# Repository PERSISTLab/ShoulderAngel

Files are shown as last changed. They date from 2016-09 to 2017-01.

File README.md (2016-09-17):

# Shoulder Angel: An Open Platform for Reprogramming Wayward Wireless Sensors

Software bugs are a critical threat to the deployability and maintainability of low-power wireless sensors, resulting in excess power consumption, hardware misconfigurations, incorrect data, and shortened device lifetimes. Worse, these errors can prevent wireless reprogramming, resulting in longer delays and costly human interventions. This repository contains the  Shoulder Angel—an ultra-low-power, low-cost, open hardware and software platform that ensures users can always recover and reprogram wireless sensors, in spite of software errors. Shoulder Angel uses a physically separate coprocessor to monitor a device’s power consumption and other behaviors, while keeping the device in a reprogrammable state. Our results show that Shoulder Angel is able to recover from otherwise fatal software errors while incurring an energy overhead of only 7 μW.

### Getting Started
Coming soon....

### License

```
Copyright (c) 2016 PERSIST Lab

Permission is hereby granted, free of charge, to any person obtaining a copy of this software 
and associated documentation files (the "Software"), to deal in the Software without restriction, 
including without limitation the rights to use, copy, modify, merge, publish, distribute, sublicense,
and/or sell copies of the Software, and to permit persons to whom the Software is furnished to do 
so, subject to the following conditions:

The above copyright notice and this permission notice shall be included in all copies or substantial
portions of the Software.

THE SOFTWARE IS PROVIDED "AS IS", WITHOUT WARRANTY OF ANY KIND, EXPRESS OR IMPLIED, 
INCLUDING BUT NOT LIMITED TO THE WARRANTIES OF MERCHANTABILITY, FITNESS FOR A PARTICULAR
PURPOSE AND NONINFRINGEMENT. IN NO EVENT SHALL THE AUTHORS OR COPYRIGHT HOLDERS BE LIABLE
FOR ANY CLAIM, DAMAGES OR OTHER LIABILITY, WHETHER IN AN ACTION OF CONTRACT, TORT OR 
OTHERWISE, ARISING FROM, OUT OF OR IN CONNECTION WITH THE SOFTWARE OR THE USE OR OTHER 
DEALINGS IN THE SOFTWARE.
```

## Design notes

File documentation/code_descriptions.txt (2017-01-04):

This is outdated and will be updaed soon.

1) Shoulder Angel code - embedded C code that will actually run on the shoulder angel device
2) Set golden image code - regular C code that runs on a laptop/computer. This is used to take an embedded C file intended to be run on an msp430 and puts it in a format so that it cna be reprogrammed onto an msp430 from another msp430.
3) Evaluation code - various code that will run on various devices for the evaluation setup.

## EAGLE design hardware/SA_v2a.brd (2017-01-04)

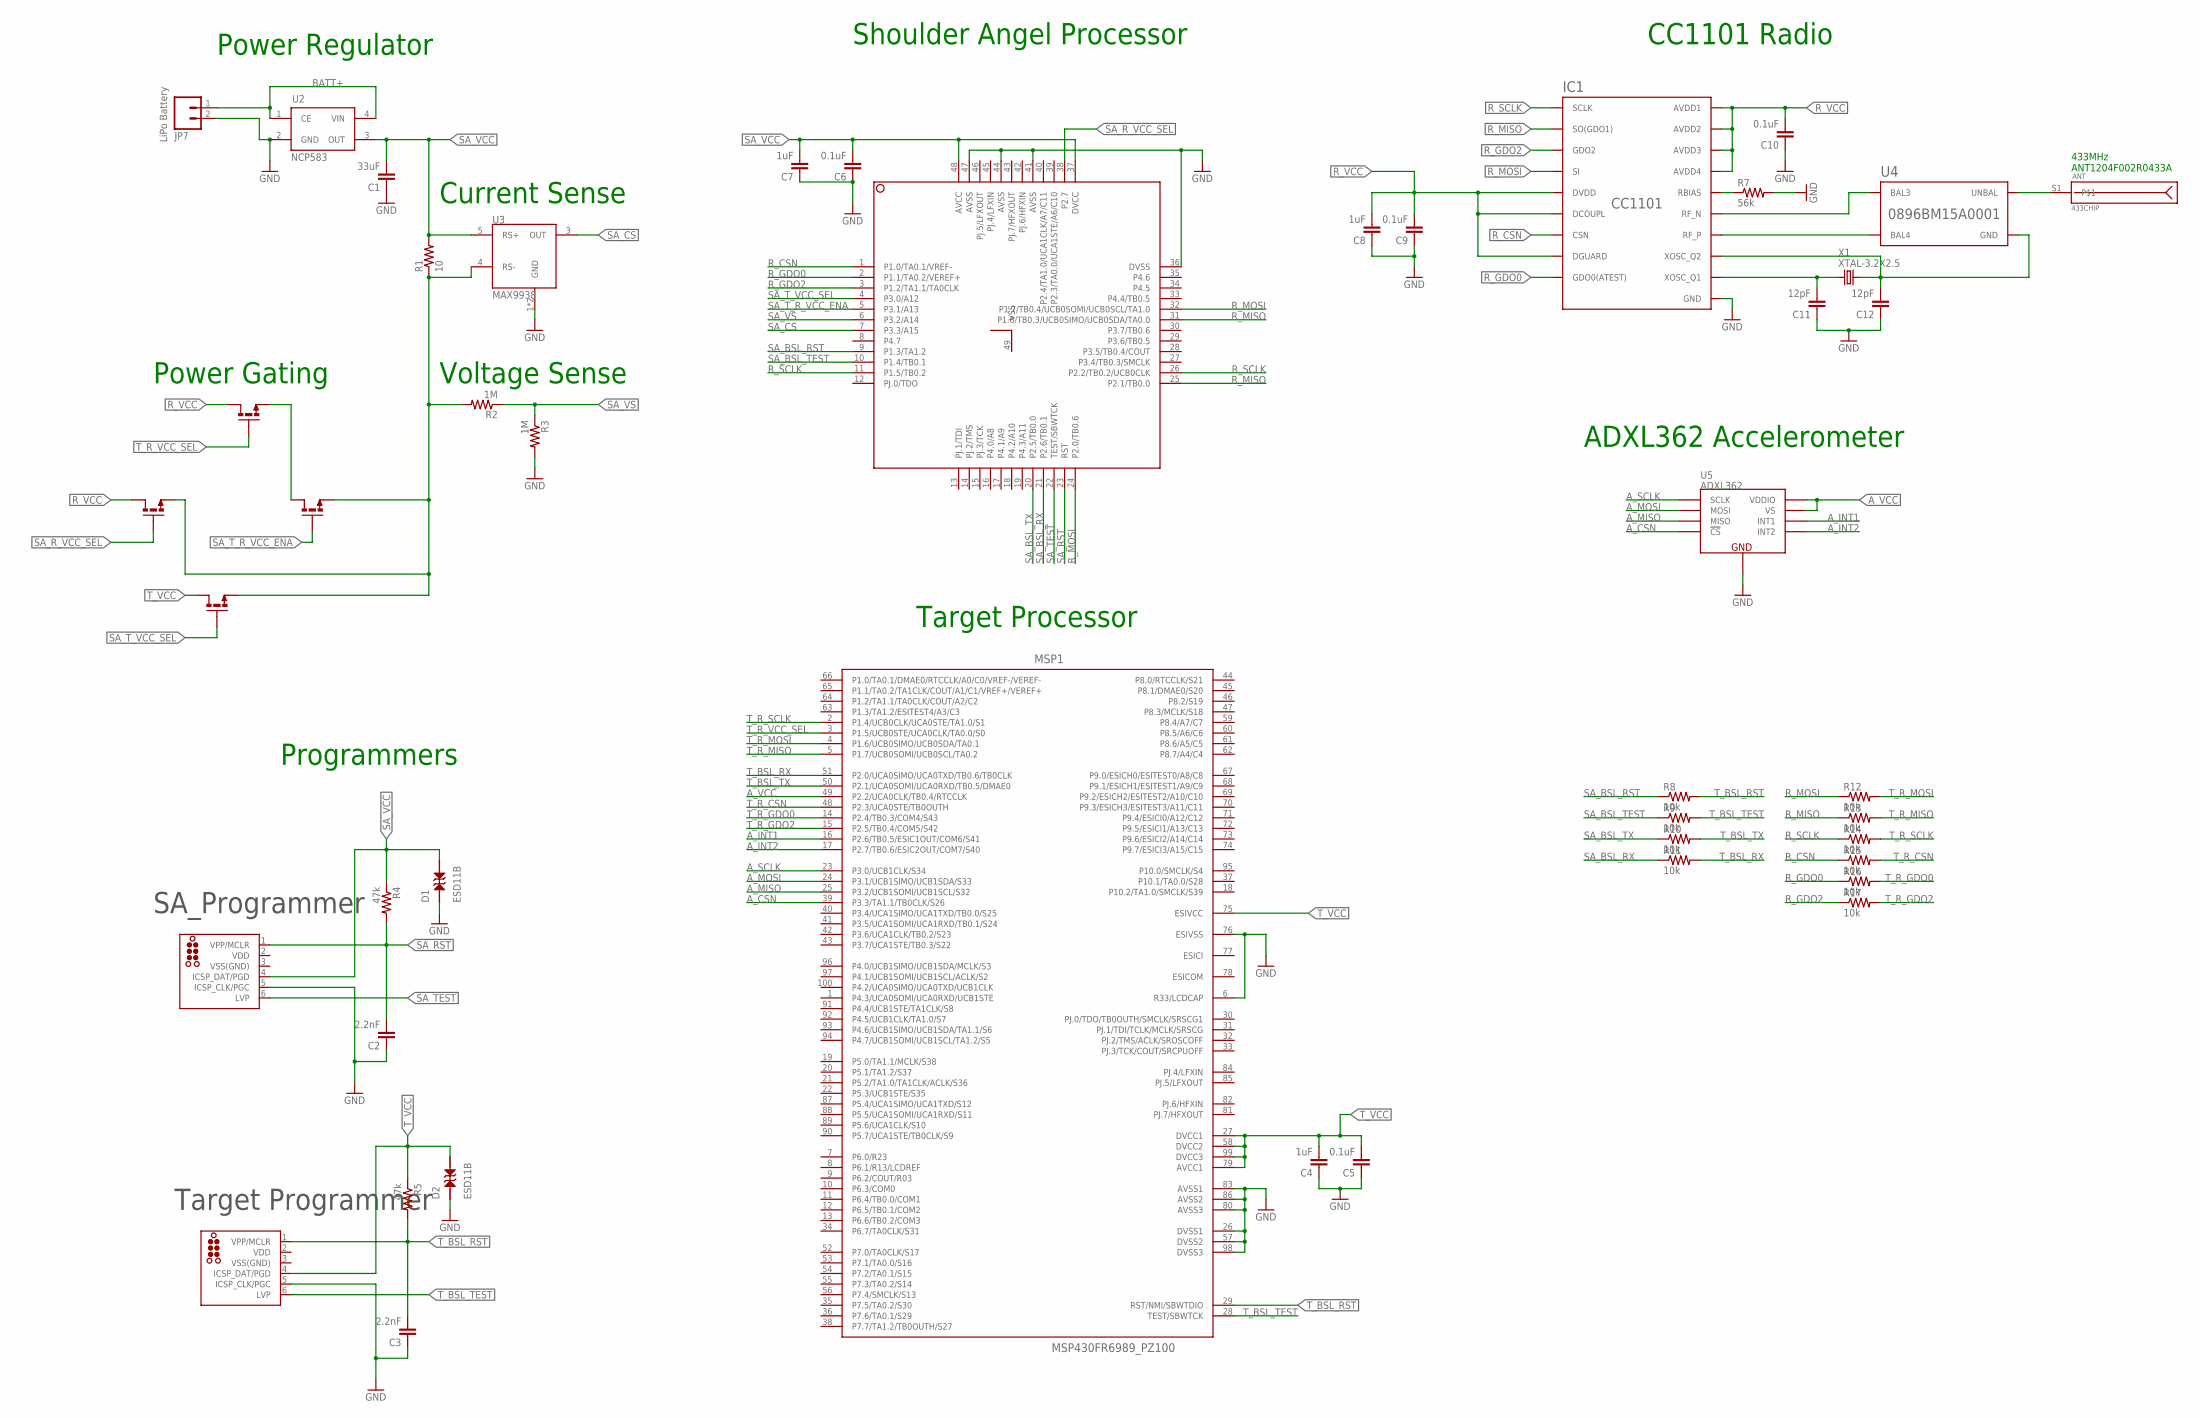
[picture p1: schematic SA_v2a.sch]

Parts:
ANT: 433CHIP; ANT-433-USP; DIGIKEY ANT-433-USP-ND
C1: 33uF; 0805; DIGIKEY 445-5986-1-ND
C2, C3: 2.2nF; 0402; DIGIKEY 311-1037-1-ND
C4, C7, C8: 1uF; 0402; DIGIKEY 311-1439-1-ND
C5, C6, C9, C10: 0.1uF; 0402; DIGIKEY 311-1338-1-ND
C11, C12: 12pF; 0402; DIGIKEY 1276-1178-1-ND
D1, D2: ESD11B; DSN2; DIGIKEY ESD11B5.0ST5GOSCT-ND
IC1: CC1101; QLP20; DIGIKEY 296-35718-1-ND
J1, J2: TC2030-MCP-NL
JP7: LiPo Battery; JST-2-SMD; DIGIKEY 455-1749-1-ND
MSP1: MSP430FR6989_PZ100; PZ100; DIGIKEY 296-38379-5-ND
R1: 10; 0402; DIGIKEY YAG3340CT-ND
R2, R3: 1M; 0402; DIGIKEY 311-1.00MLRCT-ND
R4, R5: 47k; 0402; DIGIKEY 311-47.0KLRCT-ND
R7: 56k; 0402; DIGIKEY 311-56KJRCT-ND
R8, R9, R10, R11, R12, R13, R14, R15, R16, R17: 10k; 0402; DIGIKEY 311-10KJRCT-ND
U1: MSP430FR5969_RGZ_48; RGZ48_4P1X4P1; DIGIKEY 296-37875-1-ND
U2: NCP583; SC82-AB_1PRIMARY; DIGIKEY NCP583SQ33T1GOSCT-ND
U3: MAX9938; SOT23-5; DIGIKEY MAX9938WEUK+TCT-ND
U4: 0896BM15A0001; XXXXBM15A0001; DIGIKEY 712-1474-1-ND
U5: ADXL362; DIGIKEY ADXL362BCCZ-RL7CT-ND
U$1, U$2: FDG6303N; SC70-6; DIGIKEY FDG6303NCT-ND
X1: XTAL-3.2X2.5; DIGIKEY 644-1261-1-ND

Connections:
A_CSN: MSP1.39 (P3.3/TA1.1/TB0CLK/S26), U5.P$8 (!CS)
A_INT1: MSP1.16 (P2.6/TB0.5/ESIC1OUT/COM6/S41), U5.P$11 (INT1)
A_INT2: MSP1.17 (P2.7/TB0.6/ESIC2OUT/COM7/S40), U5.P$9 (INT2)
A_MISO: MSP1.25 (P3.2/UCB1SOMI/UCB1SCL/S32), U5.P$7 (MISO)
A_MOSI: MSP1.24 (P3.1/UCB1SIMO/UCB1SDA/S33), U5.P$6 (MOSI)
A_SCLK: MSP1.23 (P3.0/UCB1CLK/S34), U5.P$4 (SCLK)
A_VCC: MSP1.49 (P2.2/UCA0CLK/TB0.4/RTCCLK), U5.P$1 (VDDIO), U5.P$14 (VS)
BATT+: JP7.1, U2.1 (CE), U2.4 (VIN)
GND: C1.1, C2.1, C3.1, C4.1, C5.1, C6.1, C7.1, C8.1, C9.1, C10.1, C11.1, C12.1, D1.P$1 (1), D2.P$1 (1), IC1.16 (GND), IC1.19 (GND), IC1.GND, IC1.GND1 (GND), IC1.GND2 (GND), IC1.GND3 (GND), IC1.GND4 (GND), IC1.GND5 (GND), J1.5 (ICSP_CLK/PGC), J2.5 (ICSP_CLK/PGC), JP7.2, MSP1.6 (R33/LCDCAP), MSP1.26 (DVSS1), MSP1.57 (DVSS2), MSP1.76 (ESIVSS), MSP1.80 (AVSS3), MSP1.83 (AVSS1), MSP1.86 (AVSS2), MSP1.98 (DVSS3), R3.2, R7.2, U1.36 (DVSS), U1.41 (AVSS), U1.44 (AVSS), U1.47 (AVSS), U2.2 (GND), U3.1 (GND), U3.2 (GND), U5.P$12 (GND), U5.P$13 (GND), U5.P$16 (GND)
unnamed: IC1.17 (RBIAS), R7.1
unnamed: IC1.12 (RF_P), U4.4 (BAL4)
unnamed: R1.1, R2.2, U3.4 (RS-), U$1.4 (S1), U$2.1 (S2), U$2.4 (S1)
unnamed: U$1.1 (S2), U$1.3 (D1)
unnamed: IC1.13 (RF_N), U4.3 (BAL3)
unnamed: C12.2, IC1.10 (XOSC_Q2), U4.2 (GND), U4.5 (GND), U4.6 (GND), X1.3 (2)
unnamed: C11.2, IC1.8 (XOSC_Q1), X1.1
unnamed: ANT.S1, U4.1 (UNBAL)
R_CSN: IC1.7 (CSN), R15.1, U1.1 (P1.0/TA0.1/VREF-)
R_GDO0: IC1.6 (GDO0(ATEST)), R16.1, U1.2 (P1.1/TA0.2/VEREF+)
R_GDO2: IC1.3 (GDO2), R17.1, U1.3 (P1.2/TA1.1/TA0CLK)
R_MISO: IC1.2 (SO(GDO1)), R13.1, U1.25 (P2.1/TB0.0), U1.31 (P1.6/TB0.3/UCB0SIMO/UCB0SDA/TA0.0)
R_MOSI: IC1.20 (SI), R12.1, U1.24 (P2.0/TB0.6), U1.32 (P1.7/TB0.4/UCB0SOMI/UCB0SCL/TA1.0)
R_SCLK: IC1.1 (SCLK), R14.1, U1.11 (P1.5/TB0.2), U1.26 (P2.2/TB0.2/UCB0CLK)
R_VCC: C8.2, C9.2, C10.2, IC1.4 (DVDD), IC1.5 (DCOUPL), IC1.9 (AVDD1), IC1.11 (AVDD2), IC1.14 (AVDD3), IC1.15 (AVDD4), IC1.18 (DGUARD), U$1.6 (D2), U$2.6 (D2)
SA_BSL_RST: R8.1, U1.9 (P1.3/TA1.2)
SA_BSL_RX: R11.1, U1.21 (P2.6/TB0.1)
SA_BSL_TEST: R9.1, U1.10 (P1.4/TB0.1)
SA_BSL_TX: R10.1, U1.20 (P2.5/TB0.0)
SA_CS: U1.7 (P3.3/A15), U3.3 (OUT)
SA_RST: C2.2, J1.1 (VPP/MCLR), R4.2, U1.23 (RST)
SA_R_VCC_SEL: U1.38 (P2.7), U$2.2 (G2)
SA_TEST: J1.6 (LVP), U1.22 (TEST/SBWTCK)
SA_T_R_VCC_ENA: U1.5 (P3.1/A13), U$1.5 (G1)
SA_T_VCC_SEL: U1.4 (P3.0/A12), U$2.5 (G1)
SA_VCC: C1.2, C6.2, C7.2, D1.P$2 (2), J1.4 (ICSP_DAT/PGD), R1.2, R4.1, U1.37 (DVCC), U1.48 (AVCC), U2.3 (OUT), U3.5 (RS+)
SA_VS: R2.1, R3.1, U1.6 (P3.2/A14)
T_BSL_RST: C3.2, J2.1 (VPP/MCLR), MSP1.29 (RST/NMI/SBWTDIO), R5.2, R8.2
T_BSL_RX: MSP1.51 (P2.0/UCA0SIMO/UCA0TXD/TB0.6/TB0CLK), R11.2
T_BSL_TEST: J2.6 (LVP), MSP1.28 (TEST/SBWTCK), R9.2
T_BSL_TX: MSP1.50 (P2.1/UCA0SOMI/UCA0RXD/TB0.5/DMAE0), R10.2
T_R_CSN: MSP1.48 (P2.3/UCA0STE/TB0OUTH), R15.2
T_R_GDO0: MSP1.14 (P2.4/TB0.3/COM4/S43), R16.2
T_R_GDO2: MSP1.15 (P2.5/TB0.4/COM5/S42), R17.2
T_R_MISO: MSP1.5 (P1.7/UCB0SOMI/UCB0SCL/TA0.2), R13.2
T_R_MOSI: MSP1.4 (P1.6/UCB0SIMO/UCB0SDA/TA0.1), R12.2
T_R_SCLK: MSP1.2 (P1.4/UCB0CLK/UCA0STE/TA1.0/S1), R14.2
T_R_VCC_SEL: MSP1.3 (P1.5/UCB0STE/UCA0CLK/TA0.0/S0), U$1.2 (G2)
T_VCC: C4.2, C5.2, D2.P$2 (2), J2.4 (ICSP_DAT/PGD), MSP1.27 (DVCC1), MSP1.58 (DVCC2), MSP1.75 (ESIVCC), MSP1.79 (AVCC1), MSP1.99 (DVCC3), R5.1, U$2.3 (D1)
VDD: J1.2 (VDD), J2.2 (VDD)
VSS(GND): J1.3 (VSS(GND)), J2.3 (VSS(GND))

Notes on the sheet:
433MHz ANT1204F002R0433A
Power Regulator
Current Sense
Voltage Sense
Power Gating
Shoulder Angel Processor
CC1101 Radio
ADXL362 Accelerometer
Target Processor
Programmers
SA_Programmer
Target Programmer

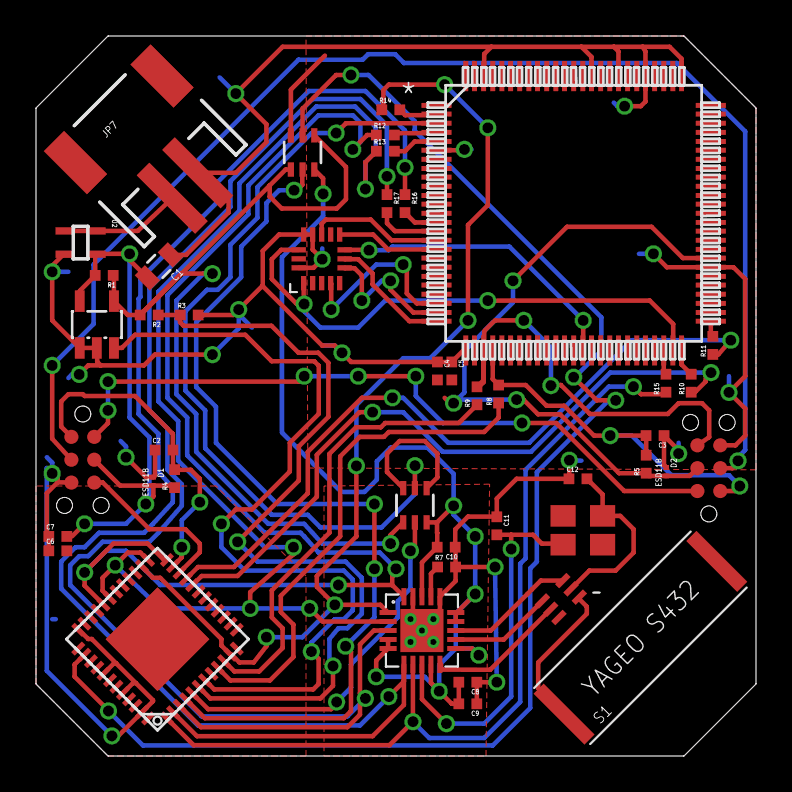
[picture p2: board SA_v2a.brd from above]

Board: 2 copper layers, 40.0 x 40.0 mm, 44 parts (0 on the bottom side), 50 nets.

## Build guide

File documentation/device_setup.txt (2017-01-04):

Outdated. Will fix that soon

Last updated: Aug 7, 2015
This document is a work in progress

This document describes the way that devices are physically connected and otherwise setup for shoulder angel.

Current List of devices
1. 2 msp430fr5969s
2. 2 msp430fr5739s (this will change)
3. 1 teensy 3.1
4. 2 CC1101 radios
5. 2 INA169 current sensors

TODO: descriptions of connections between devices

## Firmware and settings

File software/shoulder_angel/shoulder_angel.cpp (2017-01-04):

#include "pins.h"
#include "lib_spi.h"
#include "lib_cc1101.h"
#include "lib_clock.h"
#include "lib_led.h"
#include "lib_uart.h"
#include "lib_bsl.h"
#include "lib_adc.h"
#include "lib_general_definitions.h"
#include "cc1101_registers.h"

#include "radio_tests_info.h" // for radio test testing

#include "shoulder_angel.h"
#include "goldenImage.dat"

/* What currently works and doesn't
 - Reprogramming - works (
        - but doesn't if you power cycle off SA and turn it back on again 
        - you CAN reprogram multiple times as long as you don't lose power
        - probably not intitializing something correctly
 - spiTxSnooping - works
 - spiRxSnooping - works
 - handshake     - works
 - radio takeover - works
 - power monitoring - untested
 - receive update - works
        - target must handshake correctly (or not use radio at all)
        - Only confirmed to work with the t_handshake image

 Current Bugs (TODO)
 - Reprogramming doesn't work after power cycling SA
 */

//TODO: make these defaults
//#ifndef PROGRAMMING_ENABLED
//  #define REPROGRAMMING_ENABLED       YES
//#endif

#define REPROGRAMMING_ENABLED       YES
#define HANDSHAKE_ENABLED           NO
#define RADIO_TAKEOVER_ENABLED      NO
#define RECEIVE_UPDATE_ENABLED      NO
#define SPI_SNOOPING_ENABLED        NO
#define POWER_MONITORING_ENABLED    YES
#define LEDS_ENABLED                YES

uint16_t adc_current_high_count;
// NOTE: NEED TO DIAL THIS IN
#define SLEEP_CURRENT_THRESHOLD_VALUE 6
#define ADC_HIGH_COUNT 4 //if it's high for 4 times in a row, it's been on too long.

/*****************************************************************************/
/* GLOBAL VARIABLES */
/*****************************************************************************/
// Periphrial Stacks
cc1101_stack_t __radio__;
bsl_stack_t __bslStack__;
spi_stack_t __spiSnoopTx__;
spi_stack_t __spiSnoopRx__;

// Periphrial Stack Pointers
cc1101_stack_t *radio;
bsl_stack_t *bslStack;
spi_stack_t *spiSnoopTx;
spi_stack_t *spiSnoopRx;

// Mode PQ Variables
#define MODE_PQ_SIZE 100
volatile uint8_t modePq[MODE_PQ_SIZE] = {0};
volatile uint8_t modePqHead;
volatile uint8_t modePqTail;
volatile uint8_t modePqSize;
volatile uint8_t currMode;

// Other Variables
uint8_t timerA0SetBy;
uint8_t handshakeTimerHasExpired;
uint8_t radioHasTimedOut;
uint8_t spiHasTimedOut;
uint16_t totalUpdateDataPacketsReceived;
/*****************************************************************************/
/* SLEEP FUNCTIONS */
/*****************************************************************************/
void enter_sleep (void) {
    __bis_SR_register (LPM3_bits + GIE);
    __no_operation();
}

/*****************************************************************************/
/* INITIALIZATION FUNCTIONS */
/*****************************************************************************/
void config_clock(void) {
    FRCTL0 = FRCTLPW | NWAITS_2; // FRAM can only be written at 8MHz, puts 2 no-op waits
    CLOCK_SEND_PASSWORD();
    CLOCK_DCO_SET_24MH();
    CLOCK_MCLK_SET_TO_DCO();
    CLOCK_SMCLK_SET_TO_DCO();
    CLOCK_ACLK_SET_TO_VLO();
    CLOCK_MCLK_DIV_BY_1();
    CLOCK_SMCLK_DIV_BY_2();
    TIMER_DIV_ACLK(); // div clock by setting given by user
}


void init_lpm_state (void) {
    // Set GPIO pins to low power state
    // leaving the pins at their defaults will draw more power.
    P1DIR = 0x00; //input
    P1OUT = 0x00; //would be low if it were an output. (pull down)
    P1REN = 0xFF; //pull down
    P1SEL0 = 0x00; //mode = GPIO
    P1SEL1 = 0x00; //mode = GPIO

    P2DIR = 0x00;
    P2OUT = 0x00;
    P2REN = 0xFF;
    P2SEL0 = 0x00;
    P2SEL1 = 0x00;

    P3DIR = 0x00;
    P3OUT = 0x00;
    P3REN = 0xFF;
    P3SEL0 = 0x00;
    P3SEL1 = 0x00;

    P4DIR = 0x00;
    P4OUT = 0x00;
    P4REN = 0xFF;
    P4SEL0 = 0x00;
    P4SEL1 = 0x00;
#ifdef __msp430fr6989__
    P5DIR = 0x00;
    P5OUT = 0x00;
    P5REN = 0xFF;
    P5SEL0 = 0x00;
    P5SEL1 = 0x00;

    P6DIR = 0x00;
    P6OUT = 0x00;
    P6REN = 0xFF;
    P6SEL0 = 0x00;
    P6SEL1 = 0x00;

    P7DIR = 0x00;
    P7OUT = 0x00;
    P7REN = 0xFF;
    P7SEL0 = 0x00;
    P7SEL1 = 0x00;

    P8DIR = 0x00;
    P8OUT = 0x00;
    P8REN = 0xFF;
    P8SEL0 = 0x00;
    P8SEL1 = 0x00;

    P9DIR = 0x00;
    P9OUT = 0x00;
    P9REN = 0xFF;
    P9SEL0 = 0x00;
    P9SEL1 = 0x00;

    P10DIR = 0x00;
    P10OUT = 0x00;
    P10REN = 0xFF;
    P10SEL0 = 0x00;
    P10SEL1 = 0x00;
#endif

    PJDIR = 0x00;
    PJOUT = 0x00;
    PJREN = 0xFF;
    PJSEL0 = 0x00;
    PJSEL1 = 0x00;

    // Turn off ADC
    ADC_CONVERSION_DISABLE();
    ADC_TURN_OFF();
}




/*****************************************************************************/
/* Mode Priority Queue Functions */
/*****************************************************************************/

//TODO: fix magic number
uint8_t numModesAdded[10];
// reset the mode pq
void resetModePq (void) {
    modePqHead = modePqTail = modePqSize = 0;
    uint8_t i;
    for (i = 0; i < 10; i++) {
        numModesAdded[i] = 0;
    }
}


//TODO: fix 0xF0 magic number
// add mode to the mode pq
void add_mode(uint8_t nextMode) {
    // See if it should be added to the queue
    if (numModesAdded[nextMode - 0xF0] == 0) {
        numModesAdded[nextMode - 0xF0]++;

        _DINT(); // Disable Interupts
        if (modePqSize < MODE_PQ_SIZE) {
            modePq[modePqHead] = nextMode;
            modePqSize++;
            modePqHead++;
            if (modePqHead == MODE_PQ_SIZE) {
                modePqHead = 0;
            }
        }
        _EINT(); // Enable interrupts
    }
}

// set the currMode as the next mode in the pq
// NOTE: Defaults to sleep if no next mode queued
void set_mode (void) {
    _DINT(); // Disable interrupts
    uint8_t nextMode = MODE_SLEEP;
    if (modePqSize > 0) {
        nextMode = modePq[modePqTail];
        modePqSize--;
        modePqTail++;
        if (modePqTail == MODE_PQ_SIZE) {
            modePqTail = 0;
        }
    }
    if (numModesAdded[currMode - 0xF0] > 0) {
        numModesAdded[currMode - 0xF0]--;
    }
    currMode = nextMode;
    _EINT(); // Enable Interrupts
}

/*****************************************************************************/
/* General Purpose / Calculation Functions */
/*****************************************************************************/

//Used for debugging.
void blink_forever(void) {
    LED0_SET_AS_OUTPUT();
    LED1_SET_AS_OUTPUT();
    while (1) {
        LED0_TOGGLE();
        LED1_TOGGLE();
        __delay_cycles(1000000);
    }
}

//If we get time, look into hardware CRC module for better speed.
uint16_t calcCrc (uint8_t *data, uint16_t size) {
    uint16_t crc = 0xFFFF;
    while (size) {
        crc = (uint8_t) (crc >> 8) | (crc << 8);
        crc ^= (uint8_t) *data;
        crc ^= (uint8_t) (crc & 0xff) >> 4;
        crc ^= (crc << 8) << 4;
        crc ^= ((crc & 0xff) << 4) << 1;
        size--;
        data++;
    }
    return crc;
}


/*****************************************************************************/
/* TIMER RESETS */
/*****************************************************************************/
void clear_A0_timer(void) {
    TA0CCTL0 = 0;
}
void reset_radio_takeover_timer(void) {
    TA0CCTL0 = CCIE;                          // TACCR0 interrupt enabled
    TA0CCR0 = 10000;
    TA0CTL = TASSEL_1 | MC_1;                 // ACLK, upmode
    TA0CTL |= ID__2;
    //TA0EX0 = TAIDEX_5;
    TA0EX0 = TAIDEX_0;
    timerA0SetBy = RADIO_TAKEOVER_TIMER;

}

void reset_handshake_timer(void) {
    TA0CCTL0 = CCIE;                          // TACCR0 interrupt enabled
    TA0CCR0 = 10000;
    TA0CTL = TASSEL_1 | MC_1;                 // ACLK, upmode
    TA0EX0 = TAIDEX_1;
    timerA0SetBy = HANDSHAKE_TIMER;
}

void reset_radio_receive_timeout_timer(void) {
    TA0CCTL0 = CCIE;                          // TACCR0 interrupt enabled
    TA0CCR0 = 5000;
    TA0CTL = TASSEL_1 | MC_1;                 // ACLK, upmode
    TA0EX0 = TAIDEX_0;
    timerA0SetBy = RADIO_RECEIVE_TIMEOUT;
}

void reset_update_receive_timer(void) {
    TA0CCTL0 = CCIE;                          // TACCR0 interrupt enabled
    TA0CCR0 = 15000;
    //TA0CCR0 = 1000;
    TA0CTL = TASSEL_1 | MC_1;                 // ACLK, upmode
    TA0EX0 = TAIDEX_0;
    timerA0SetBy = UPDATE_RECEIVE_TIMEOUT;
}

void reset_wait_for_spi_bytes_timer(void) {
    TA0CCTL0 = CCIE;                          // TACCR0 interrupt enabled
    TA0CCR0 = 10000;
    TA0CTL = TASSEL_1 | MC_1;                 // ACLK, upmode
    TA0EX0 = TAIDEX_0;
    timerA0SetBy = WAIT_FOR_SPI_BYTES_TIMER;
}

// Reset Current Timer
void reset_current_timer (void) {
    TA1CCTL0 = CCIE;                          // TACCR0 interrupt enabled
    TA1CCR0 = 2500;
    TA1CTL = TASSEL_1 | MC_1;                 // ACLK, upmode
    TA1EX0 = TAIDEX_0;
}

/*****************************************************************************/
/* General Purpose Radio Functions */
/* NOTE: Need to make sure that the target isnt using the radio at this time */
/*****************************************************************************/
// TODO: look into using memcmp instead (smaller?)
uint8_t compare_packets(const uint8_t *p1, uint8_t s1, const uint8_t *p2, uint8_t s2) {
    uint8_t isCorrect = CORRECT;
    uint8_t i;
    if (s1 != s2) {
        isCorrect = INCORRECT;
    } else {
        for (i = 0; i < s1; i++) {
            // Check that packet is the same as packet1
            if (p1[i] != p2[i]) {
                isCorrect = INCORRECT;
                break;
            }
        }
    }
    return isCorrect;
}


void check_received_packet (const uint8_t *p, uint8_t s) {

    uint8_t result;
    result = compare_packets (p, s,recoveryPacket, RECOVERY_PACKET_SIZE);
    if (result == CORRECT) {
        add_mode(MODE_REPROGRAM_DEVICE);
        return;
    }
    result = compare_packets (p, s, updateStartPacket, UPDATE_START_PACKET_SIZE);
    if (result == CORRECT && currMode != MODE_RECEIVE_UPDATE) {
        add_mode(MODE_RECEIVE_UPDATE);
        return;
    }

    result = compare_packets (p, s, packet1, PACKET_SIZE_1);
      if (result == CORRECT) {
      add_mode(MODE_BLINK_LED0);
      return;
      }

    /*result = compare_packets (p, s, packet2, PACKET_SIZE_2);
      if (result == CORRECT) {
      add_mode(MODE_BLINK_LED0);
      return;
      }

    result = compare_packets (p, s, packet3, PACKET_SIZE_3);
    if (result == CORRECT) {
        add_mode(MODE_BLINK_LED1);
        return;
    }*/

}


void radio_setup (void) {
    // Reset SPI
    SPI_RESET(radio->cc1101_spi);

    // Set SPI Options
    SPI_FIRST_CLK_EDGE_IS_DATA_CAPTURE(radio->cc1101_spi);
    SPI_CLK_INACTIVE_IS_LOW(radio->cc1101_spi);
    SPI_MSB_FIRST(radio->cc1101_spi);
    SPI_8BIT_CHAR(radio->cc1101_spi);
    SPI_MASTER_MODE(radio->cc1101_spi);
    SPI_3PIN_MODE(radio->cc1101_spi);
    SPI_SYNC_MODE(radio->cc1101_spi);
    SPI_SELECT_SMCLK(radio->cc1101_spi);
    SPI_SET_UCBRx(radio->cc1101_spi, 2);

    // Set Pins and ports
    spi.configure_pins_for_spi (radio->cc1101_spi);

    // Start SPI
    SPI_START(radio->cc1101_spi);
}

void radio_destruct(void) {
    CC1101_CSN_DRIVE_HIGH(radio);
    CC1101_GDO0_DRIVE_LOW(radio);
    CC1101_GDO2_DRIVE_LOW(radio);
    CC1101_CSN_CONFIG_AS_INPUT(radio);
    CC1101_GDO0_CONFIG_AS_INPUT(radio);
    CC1101_GDO2_CONFIG_AS_INPUT(radio);
    CC1101_CSN_SEL_GPIO(radio);
    CC1101_GDO0_SEL_GPIO(radio);
    CC1101_GDO2_SEL_GPIO(radio);

    spi.configure_pins_for_gpio(radio->cc1101_spi);
    SPI_RESET(radio->cc1101_spi);
}
void radio_sleep(void) {
    radio_setup();
    cc1101.init(radio);
    cc1101.idle(radio);
    cc1101.sleep(radio);
    radio_destruct();
}

void send_single_packet_over_radio (const uint8_t *p, const uint8_t s) {

    radio_setup();
    cc1101.init(radio);
    cc1101.set_logical_channel(radio, LOGICAL_CHANNEL_1); // Needs to be the same in Tx and Rx
    cc1101.set_data_rate(radio, DATA_RATE_1); // Needs to be the same in Tx and Rx
    cc1101.set_tx_power(radio, SEND_POWER_1);
    cc1101.send_data(radio, p, s);
    cc1101.idle(radio);
    cc1101.sleep(radio);
    radio_destruct();

}

//Wait for packet (with timeout)
uint8_t receive_single_packet_over_radio(uint8_t *p, uint8_t *s_ptr) {
    uint8_t result;

    radio_setup();
    cc1101.init(radio);
    cc1101.set_logical_channel(radio, LOGICAL_CHANNEL_1);
    cc1101.set_data_rate(radio, DATA_RATE_1);
    cc1101.rx_on(radio);
    radioHasTimedOut = NO;
    reset_radio_receive_timeout_timer();
    while((! cc1101.check_receive_flag(radio)) && radioHasTimedOut == NO);
    clear_A0_timer();
    if (radioHasTimedOut == NO) {
        *s_ptr = cc1101.receive_data(radio, p);
        result = PACKET_REC;
    } else {
        cc1101.rx_mode_off(radio);
        result = TIMEOUT;
    }
    cc1101.idle(radio);
    cc1101.sleep(radio);
    radio_destruct();   // Turn radio off

    return result;
}

/*****************************************************************************/
/* BSL - BOOTLOADER */
/*****************************************************************************/
void bsl_uart_setup_9600baud(void) {
    // Reset UART
    UART_RESET (bslStack->bsl_uart);

    // Set UART Options
    UART_PARITY_BIT_ENABLE(bslStack->bsl_uart);
    UART_EVEN_PARITY(bslStack->bsl_uart);
    UART_LSB_FIRST(bslStack->bsl_uart);
    UART_8BIT_CHAR(bslStack->bsl_uart);
    UART_1_STOP_BIT(bslStack->bsl_uart);
    UART_SET_UART_MODE(bslStack->bsl_uart);
    UART_ASYNC_MODE(bslStack->bsl_uart);
    UART_SELECT_SMCLK(bslStack->bsl_uart);
    UART_ERROR_CHAR_INT_DISABLE(bslStack->bsl_uart);
    UART_BREAK_CHAR_INT_DISABLE(bslStack->bsl_uart);
    UART_NOT_DORMANT(bslStack->bsl_uart);
    UART_NEXT_FRAME_IS_DATA(bslStack->bsl_uart);
    UART_NEXT_FRAME_IS_NOT_BREAK(bslStack->bsl_uart);

    UART_OVERSAMPLING_ENABLED(bslStack->bsl_uart);
    UART_SET_UCBRx(bslStack->bsl_uart, 78);
    UART_SET_UCBRFx(bslStack->bsl_uart, 2);
    UART_SET_UCBRSx(bslStack->bsl_uart, 0x00);

    // Set pins and ports
    uart.configure_pins (bslStack->bsl_uart);

    // Start Uart
    UART_START(bslStack->bsl_uart);
}

void bsl_uart_setup_115200baud(void) {

    // Reset UART
    UART_RESET (bslStack->bsl_uart);

    // Set UART Options
    UART_PARITY_BIT_ENABLE(bslStack->bsl_uart);
    UART_EVEN_PARITY(bslStack->bsl_uart);
    UART_LSB_FIRST(bslStack->bsl_uart);
    UART_8BIT_CHAR(bslStack->bsl_uart);
    UART_1_STOP_BIT(bslStack->bsl_uart);
    UART_SET_UART_MODE(bslStack->bsl_uart);
    UART_ASYNC_MODE(bslStack->bsl_uart);
    UART_SELECT_SMCLK(bslStack->bsl_uart);
    UART_ERROR_CHAR_INT_DISABLE(bslStack->bsl_uart);
    UART_BREAK_CHAR_INT_DISABLE(bslStack->bsl_uart);
    UART_NOT_DORMANT(bslStack->bsl_uart);
    UART_NEXT_FRAME_IS_DATA(bslStack->bsl_uart);
    UART_NEXT_FRAME_IS_NOT_BREAK(bslStack->bsl_uart);

    UART_OVERSAMPLING_ENABLED(bslStack->bsl_uart);
    UART_SET_UCBRx(bslStack->bsl_uart, 6);
    UART_SET_UCBRFx(bslStack->bsl_uart, 8);
    UART_SET_UCBRSx(bslStack->bsl_uart, 0x20);

    // Set pins and ports
    uart.configure_pins (bslStack->bsl_uart);

    // Start Uart
    UART_START(bslStack->bsl_uart);
}

void bsl_setup (void) {
    // we have to start in slow mode (9600 baud)
    bsl_uart_setup_9600baud();

    // Enable Uart interrupt
    UART_RX_INT_ENABLE(bslStack->bsl_uart);
}


void reset_target_device (void) {
    UART_TXD_SEL_GPIO(bslStack->bsl_uart);
    UART_RXD_SEL_GPIO(bslStack->bsl_uart);
    UART_TXD_DRIVE_LOW(bslStack->bsl_uart);
    UART_RXD_DRIVE_LOW(bslStack->bsl_uart);
    UART_TXD_CONFIG_AS_INPUT(bslStack->bsl_uart);
    UART_RXD_CONFIG_AS_INPUT(bslStack->bsl_uart);

    BSL_TEST_CONFIG_AS_INPUT(bslStack);
    BSL_TEST_DRIVE_LOW(bslStack);

    BSL_RST_CONFIG_AS_OUTPUT(bslStack);
    BSL_RST_DRIVE_HIGH(bslStack);
    __delay_cycles(100);
    BSL_RST_DRIVE_LOW(bslStack);
    __delay_cycles(100);
    BSL_RST_DRIVE_HIGH(bslStack);
    BSL_RST_CONFIG_AS_INPUT(bslStack);
}

// Parse through a program stored in FRAM, and prepare it for Reprogramming
// result: prog is populated.
void get_program (prog_parser_t *prog, uint8_t prog_num, uint8_t origOrRec) {
    uint8_t i;
    uint32_t addr;

    // Set header to address to get the info
    if (origOrRec == RECEIVED_PROGRAMS) {
        prog->header = (prog_header_t *) &update_prog_addr[0];
    } else {
        prog->header = (prog_header_t *) &orig_prog_addr[0];
    }

    // Jump from header to header till at the right one
    for (i = 0; i < prog_num; i++) {
        addr = (uint32_t) (prog->header);
        addr += sizeof (prog_header_t);
        addr += prog->header->numCommands * sizeof (uint16_t);
        addr += prog->header->size;
        prog->header = (prog_header_t *) addr;
    }

    // Set the pointers to the commandSizes and commandBin (hacky address fun fun)
    prog->commandSizes = (uint16_t *) (&(prog->header[1]));
    prog->commandBin = (uint8_t *) (&(prog->commandSizes[prog->header->numCommands]));
}
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
int main (void) {

    //Stop watchdog timer
    WDTCTL = WDTPW + WDTHOLD;
    PM5CTL0 &= ~LOCKLPM5;

    // Config Clock
    config_clock();

    reset_system();

    add_mode(MODE_REPROGRAM_DEVICE);
    while (1) {
        set_mode();
        switch (currMode){
#if SPI_SNOOPING_ENABLED == YES
            case MODE_START_SPI_SNOOPING :
                spi_snoop_setup();
                break;

            case MODE_SNOOP_RADIO_DATA :
                spi_snoop_radio();
                break;
#endif

            // TODO: Make a way for this to happen or remove
            case MODE_STOP_SPI_SNOOPING :
                spi_snoop_destruct();
                break;

            case MODE_REPROGRAM_DEVICE :
#if REPROGRAMMING_ENABLED == YES
                reprogram_device(ORIGINAL_PROGRAMS, 0);
                reset_system();
                LED0_SET_AS_OUTPUT();
                LED1_SET_AS_OUTPUT();

                LED0_DRIVE_LOW();
                LED1_DRIVE_LOW();

#endif
                break;

            case MODE_RADIO_TAKEOVER :
#if RADIO_TAKEOVER_ENABLED == YES
                radio_takeover();
                reset_radio_takeover_timer();
                //add_mode(MODE_REPROGRAM_DEVICE);
#endif
                break;

            case MODE_RECEIVE_UPDATE :
#if RECEIVE_UPDATE_ENABLED == YES
                clear_A0_timer();
                receive_update();
                reset_radio_takeover_timer();
#endif
                break;

            case MODE_READ_CURRENT :
#if POWER_MONITORING_ENABLED == YES
                take_current_reading();
                reset_current_timer();
#endif
                break;
#if LEDS_ENABLED == YES
            case MODE_BLINK_LED0 :
                LED0_TOGGLE();
                break;

            case MODE_BLINK_LED1 :
                LED1_TOGGLE();
                break;
#endif
            case MODE_SLEEP :
                enter_sleep();
        }
    }
}

/*****************************************************************************/
/* INTERRUPTS */
/*****************************************************************************/
void __attribute__ ((interrupt (__USCI_BSL_VECTOR__))) BSL_ISR (void);
void BSL_ISR (void) {
    uart.isr(bslStack->bsl_uart);
}

void __attribute__ ((interrupt (__USCI_SPI_SNOOP_RX_VECTOR__))) SPI_SNOOP_ISR (void);
void SPI_SNOOP_ISR (void) {
    spi.slave_isr(spiSnoopTx);
    spi.slave_isr(spiSnoopRx);
    add_mode(MODE_SNOOP_RADIO_DATA);
    LPM3_EXIT;
}

// Timer A0 interrupt service routine
void __attribute__ ((interrupt(TIMER0_A0_VECTOR))) Timer_A_ISR (void) {
    TA0CTL = 0;
    TA0CTL &= ~TAIFG;
    LPM3_EXIT;
    if (timerA0SetBy == RADIO_TAKEOVER_TIMER) {
        add_mode(MODE_RADIO_TAKEOVER);
    } else if (timerA0SetBy == HANDSHAKE_TIMER) {
        handshakeTimerHasExpired = YES;
    } else if (timerA0SetBy == RADIO_RECEIVE_TIMEOUT) {
        radioHasTimedOut = YES;
    } else if (timerA0SetBy == UPDATE_RECEIVE_TIMEOUT) {
        radioHasTimedOut = YES;
    } else if (timerA0SetBy == WAIT_FOR_SPI_BYTES_TIMER) {
        spiHasTimedOut = YES;
    }
}

// Timer ISR for current reading
void __attribute__ ((interrupt(TIMER1_A0_VECTOR))) Timer1_A0_ISR (void) {
    TA1CTL = 0;
    TA1CTL &= ~TAIFG;
    add_mode(MODE_READ_CURRENT);
    LPM3_EXIT;
}

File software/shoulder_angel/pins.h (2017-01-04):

#ifndef __BITS
#define __BITS

#ifdef __launch5969_v1__

#include <msp430fr5969.h>
#define TARGET_VCC_PORT__       4
#define TARGET_VCC_PIN__        2
#define RADIO_VCC_PORT__        1
#define RADIO_VCC_PIN__         2
#define T_RADIO_ENA_PORT__ 3
#define T_RADIO_ENA_PIN__  0

#define BSL_UC_ID__         __A1__
#define __USCI_BSL_VECTOR__ USCI_A1_VECTOR
#define BSL_RST_PORT__      1
#define BSL_RST_PIN__       3
#define BSL_TEST_PORT__     1
#define BSL_TEST_PIN__      4

#define RADIO_UC_ID__       __A0__
#define RADIO_CSN_PORT__    3
#define RADIO_CSN_PIN__     4
#define RADIO_GDO0_PORT__   3
#define RADIO_GDO0_PIN__    5
#define RADIO_GDO2_PORT__   3
#define RADIO_GDO2_PIN__    6

#define SNOOP_TX_UC_ID__                RADIO_UC_ID__
#define SNOOP_RX_UC_ID__                __B0__
#define __USCI_SPI_SNOOP_RX_VECTOR__    USCI_B0_VECTOR

#endif
///////////////////////////Nicole's Attempt///////////////////////////////////
#ifdef __launch5989_v1__

#include <msp430fr5989.h>
#define TARGET_VCC_PORT__       5	
#define TARGET_VCC_PIN__        3	

#define RADIO_VCC_PORT__        4	
#define RADIO_VCC_PIN__         0	

#define T_RADIO_ENA_PORT__  4		
#define T_RADIO_ENA_PIN__   1		

#define CURR_SENSE_PORT__   9		
#define CURR_SENSE_PIN__    6		
#define MCTL0_SEL_CURR_SENSE_ADC()    ADC_MCTL0_SEL_A14();  

#define VOLT_SENSE_PORT__   9		
#define VOLT_SENSE_PIN__    7		

#define BSL_UC_ID__         __A0__ 	
#define __USCI_BSL_VECTOR__ USCI_A0_VECTOR 

#define BSL_RST_PORT__      3  	
#define BSL_RST_PIN__       5	

#define BSL_TEST_PORT__     3	
#define BSL_TEST_PIN__      4	

#define RADIO_UC_ID__       __B0__  

#define RADIO_CSN_PORT__    2	
#define RADIO_CSN_PIN__     4	

#define RADIO_GDO0_PORT__   2	
#define RADIO_GDO0_PIN__    5	

#define RADIO_GDO2_PORT__   2	
#define RADIO_GDO2_PIN__    6	

#define SNOOP_TX_UC_ID__                RADIO_UC_ID__
#define SNOOP_RX_UC_ID__                __B1__ 

#define __USCI_SPI_SNOOP_RX_VECTOR__    USCI_B1_VECTOR  

#endif
///////////////////////////Nicole's Attempt///////////////////////////////////


#ifdef __launch6989_v1__

#include <msp430fr6989.h>
#define TARGET_VCC_PORT__       4
//#define TARGET_VCC_PORT__       5
#define TARGET_VCC_PIN__        3

#define RADIO_VCC_PORT__        4
#define RADIO_VCC_PIN__         0

#define T_RADIO_ENA_PORT__  4
#define T_RADIO_ENA_PIN__   1

#define CURR_SENSE_PORT__   9
#define CURR_SENSE_PIN__    6
#define MCTL0_SEL_CURR_SENSE_ADC()    ADC_MCTL0_SEL_A14();

#define VOLT_SENSE_PORT__   9
#define VOLT_SENSE_PIN__    7

#define BSL_UC_ID__         __A0__
#define __USCI_BSL_VECTOR__ USCI_A0_VECTOR

#define BSL_RST_PORT__      3
#define BSL_RST_PIN__       6
//#define BSL_RST_PIN__       5

#define BSL_TEST_PORT__     3
#define BSL_TEST_PIN__      7
//#define BSL_TEST_PIN__      4

#define RADIO_UC_ID__       __B0__

#define RADIO_CSN_PORT__    2
#define RADIO_CSN_PIN__     4

#define RADIO_GDO0_PORT__   2
#define RADIO_GDO0_PIN__    5

#define RADIO_GDO2_PORT__   2
#define RADIO_GDO2_PIN__    6

#define SNOOP_TX_UC_ID__                RADIO_UC_ID__
#define SNOOP_RX_UC_ID__                __B1__

#define __USCI_SPI_SNOOP_RX_VECTOR__    USCI_B1_VECTOR

#endif

// Pins to Bits
#define TARGET_VCC_BIT__    BV(TARGET_VCC_PIN__)
#define RADIO_VCC_BIT__     BV(RADIO_VCC_PIN__)
#define T_RADIO_ENA_BIT__   BV(T_RADIO_ENA_PIN__)
#define BSL_RST_BIT__       BV(BSL_RST_PIN__)
#define BSL_TEST_BIT__      BV(BSL_TEST_PIN__)
#define RADIO_CSN_BIT__     BV(RADIO_CSN_PIN__)
#define RADIO_GDO0_BIT__    BV(RADIO_GDO0_PIN__)
#define RADIO_GDO2_BIT__    BV(RADIO_GDO2_PIN__)
#define CURR_SENSE_BIT__    BV(CURR_SENSE_PIN__)
#define VOLT_SENSE_BIT__    BV(VOLT_SENSE_PIN__)
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

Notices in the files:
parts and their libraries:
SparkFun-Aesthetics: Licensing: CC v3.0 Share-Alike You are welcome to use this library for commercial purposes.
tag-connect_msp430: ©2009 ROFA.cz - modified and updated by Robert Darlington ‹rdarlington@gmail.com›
